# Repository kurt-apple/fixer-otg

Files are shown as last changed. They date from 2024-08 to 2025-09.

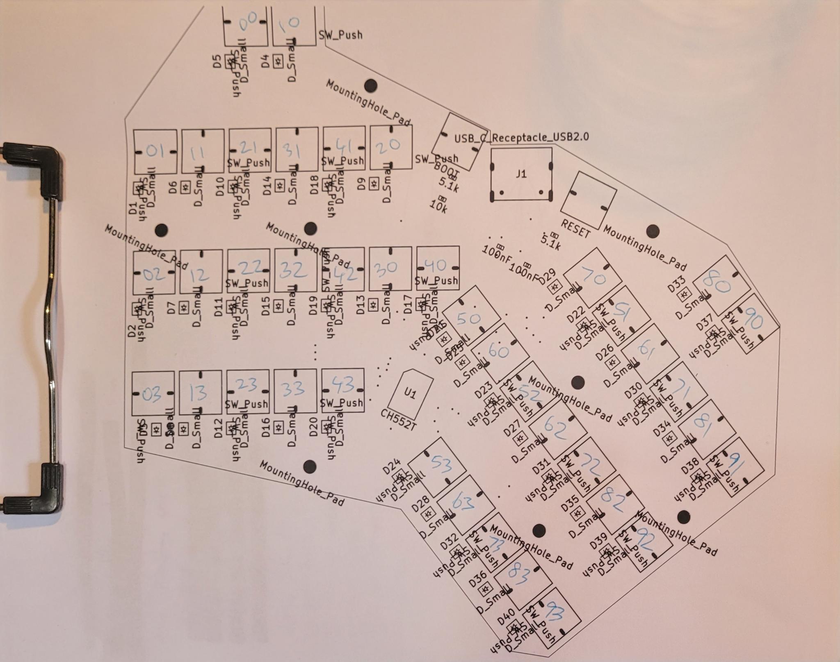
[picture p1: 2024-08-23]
pcb/layout.jpeg

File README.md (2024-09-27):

# fixer-otg
- Fork of [ChrisChrisLoLo/pusheenz40](https://github.com/ChrisChrisLoLo/pusheenz40). Also gathered info from [idawgz32](https://github.com/ChrisChrisLoLo/idawgz32) and [bunchiez40](https://github.com/ChrisChrisLoLo/bunchiez40).
- Layout is all-new, and design emphasizes ultra portable, small form factor while still having a fairly sane key map.
- Encased in epoxy for maximum durability and true pocketability
- Blog posts hosted on [Obsidian Publish](https://publish.obsidian.md/kurt/Maps/Fixer+OTG).
- **SHOWCASE MEDIA** is [here!](https://publish.obsidian.md/kurt/Pages/Fixer+OTG/Fixer+OTG+-+Showcase)
- FAK Firmware is [here!](https://github.com/kurt-apple/fak)

Fixer OTG Keyboard
Poser

# Keyboard Design
As a parent, I often find myself "nap-trapped" but still needing to do computer work. After trying several Android touchscreen keyboards I have concluded that my fingers are not up for the task anymore. However, I still require a handheld form factor. More recently I spotted the uConsole from ClockworkPi and while it looks neat, I reason that if I have to wait many months to receive one, I might as well challenge myself to DIY. What could go wrong? 

The intent is to use these schematics (bunchiez40, pusheenz40, and idawgz32) as a launching-off point for an ambitious, DIY pocket keyboard, which will later evolve into a "deck" or "pocket" pc. Some requirements are currently listed in the [TODOs](TODO.md).

# Status
- prototype keyboard PCBs were ordered, arrived, I broke board 1 and board 2 is alive and well!
- Layout and firmware are made and I can achieve ~22 WPM on this layout!
- I've got my eyes set on a few display modules and I am interested in designing a CM4 carrier or picking another small SBC to dedicate to the cyberdeck project.

# Navigating the KiCad Files
I used a plugin called "Hierarchical-PCB" which allowed me to define a subcircuit for `switch_module` in separate `kicad_pcb` and `kicad_sch` files, then copy the layout specified in that `kicad_pcb` file whenever a hierarchical sheet of the same name is placed in the schematic of another PCB. The `switch_module` contains through-holes, diode positioning, and the necessary tracks for a single key.

> [!Warning]
> "Hierarchical-PCB" does not yet support nested hierarchical sheets. I forked the project and I want to try to add this support at a later date. Nevertheless, this plugin was VERY helpful in both making the schematic visually less noisy and also in quickly laying out tedious portions of the keyboard PCB.

To open the design I am using currently, please open the main `kicad_pcb` file titled `fixer-otg.kicad_pcb`.

# Making One
- DM me on Discord (@present_day) to check if I have any boards remaining
- Get yourself some Kailh Mute Micro Switches (42x)
- Fork my FAK repo for the firmware code, and modify however much you wish.
- Gather your soldering supplies
- My provided manufacturing files (gerber, drilling, BOM) are specifically for JLCPCB. If you want to print them at a different company you might have to output your own manufacturing files. Please note that there were a few minor corrections/alterations JLC made before finalizing their production file and proceeding to manufacturing. I am new at this - your experience may vary.
- All but the switches are placed/assembled by JLC.
- Receive your board(s)
- Recommended: flash firmware and short out each key by hand to make sure the keys work.
- Clone or fork the firmware repo and read code/make any customizations as you wish.
- `python fak.py compile -kb fixer-otg`
- plug in the board while holding the BOOT key (left of usb port)
- `python fak.py flash -kb fixer-otg`
- Solder the mute switches to each pad if you haven't done so already. Seal bottom of switches if you plan to epoxy (at your own risk!)
- Test it out

# Firmware Dependencies (Arch)
- python
- meson
- sdcc
- nickel

# BOM
This is the BOM. Note that most PCB prototype services have a minimum order quantity of around 5.
|  Comment | JLCPCB Part # | QTY | Price 5 Boards |
|---|---|---| --- |
| USB C Port | C165948 | 5 | $0.779 |
| CH552T | C111367 | 5 | $2.543 |
| 100nF Capacitor | C1525 | 10 | $0.012 |
| 5.1k Resistor | C25905 | 10 | $0.005 |
| 10k Resistor | C25744 | 5 | $0.003 |
| Diode | C2128 | 200 | $1.78 |

Some notes about my order and costs:
- PCB cost $19.60 in total for 5 boards.
- assembly cost $21.96 for 5 boards.
- shipping from JLC cost $22.80 to USA.
- the cost for switches varies widely; I bought from Kailh directly however Alibaba/Aliexpress have bulk lots of Kailh Micro switches for much cheaper.

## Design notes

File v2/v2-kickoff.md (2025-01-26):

# Kickoff: Fixer V2
The new version will be completely redone.
- PG1316M
- DIY SMT Soldering
- Wireless Split

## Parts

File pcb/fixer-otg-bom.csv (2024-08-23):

Reference | Value | Datasheet | Footprint | Qty | DNP | JLCPCB Part#
C1,C2 | 100nF | ~ | Library:C_0402_1005Metric | 2 |  | C1525
D1,D2,D3,D4,D5,D6,D7,D8,D9,D10,D11,D12,D13,D14,D15,D16,D17,D18,D19,D20,D21,D22,D23,D24,D25,D26,D27,D28,D29,D30,D31,D32,D33,D34,D35,D36,D37,D38,D39,D40 | D_Small | ~ | Library:D_SOD-323 | 40 |  | C2128
J1 | USB_C_Receptacle_USB2.0 | https://www.usb.org/sites/default/files/documents/usb_type-c.zip | Library:USB_C_Receptacle_HRO_TYPE-C-31-M-12 | 1 |  | C165948
R1,R2 | 5.1k | ~ | Library:R_0402_1005Metric | 2 |  | C25905
R3 | 10k | ~ | Library:R_0402_1005Metric | 1 |  | C25744
U1 | CH552T | http://www.wch.cn/downloads/file/241.html | Library:TSSOP-20_4.4x6.5mm_P0.65mm | 1 |  | C111367

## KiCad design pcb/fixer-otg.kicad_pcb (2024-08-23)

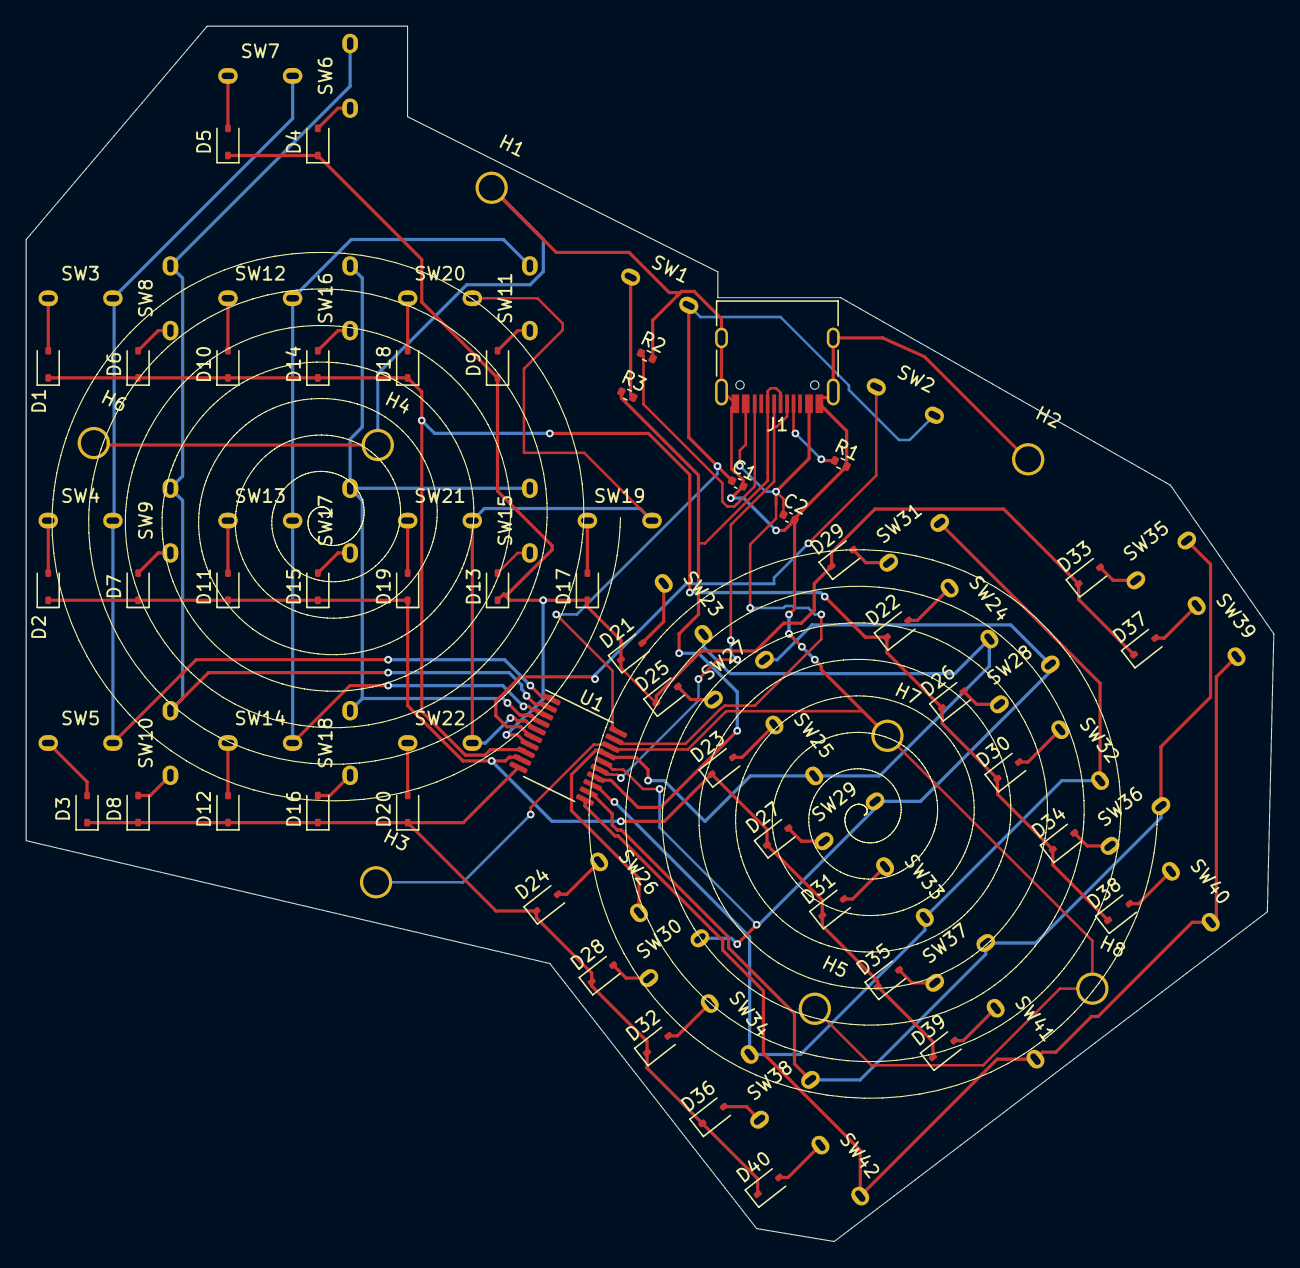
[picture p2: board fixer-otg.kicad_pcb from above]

Board: 2 copper layers, 96.5 x 94.0 mm, 97 parts (0 on the bottom side), 63 nets.

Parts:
C1, C2: 100nF; C_0402_1005Metric
D1, D2, D3, D4, D5, D6, D7, D8, D9, D10, D11, D12, D13, D14, D15, D16, D17, D18, D19, D20, D21, D22, D23, D24, D25, D26, D27, D28, D29, D30, D31, D32, D33, D34, D35, D36, D37, D38, D39, D40: D_Small; D_SOD-323
H1, H2, H3, H4, H5, H6, H7, H8: MountingHole_Pad; m1.6_hole
J1: USB_C_Receptacle_USB2.0; USB_C_Receptacle_HRO_TYPE-C-31-M-12
R1, R2: 5.1k; R_0402_1005Metric
R3: 10k; R_0402_1005Metric
SW1: BOOT; Button_Mute_Kailh
SW2: RESET; Button_Mute_Kailh
SW3, SW4, SW5, SW6, SW7, SW8, SW9, SW10, SW11, SW12, SW13, SW14, SW15, SW16, SW17, SW18, SW19, SW20, SW21, SW22, SW23, SW24, SW25, SW26, SW27, SW28, SW29, SW30, SW31, SW32, SW33, SW34, SW35, SW36, SW37, SW38, SW39, SW40, SW41, SW42: SW_Push; Button_Mute_Kailh
U1: CH552T; TSSOP-20_4.4x6.5mm_P0.65mm

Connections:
+3.3V: C1.1, SW1.2, SW2.2, U1.20 (V33)
BOOT: R3.2, SW1.1
CC1: J1.A5 (CC1), R1.1
CC2: J1.B5 (CC2), R2.1
GND: C1.2, C2.2, H1.1, H2.1, H3.1, H4.1, H5.1, H6.1, H7.1, H8.1, J1.A1 (GND), J1.A12 (GND), J1.B1 (GND), J1.B12 (GND), J1.S1 (SHIELD), R1.2, R2.2, U1.18 (GND/VSS)
unnamed: D1.2 (A), SW3.1
unnamed: D2.2 (A), SW4.1
unnamed: D3.2 (A), SW5.1
unnamed: D4.2 (A), SW6.1
unnamed: D5.2 (A), SW7.1
unnamed: D6.2 (A), SW8.1
unnamed: D7.2 (A), SW9.1
unnamed: D8.2 (A), SW10.1
unnamed: D9.2 (A), SW11.1
unnamed: D10.2 (A), SW12.1
unnamed: D11.2 (A), SW13.1
unnamed: D12.2 (A), SW14.1
unnamed: D13.2 (A), SW15.1
unnamed: D14.2 (A), SW16.1
unnamed: D15.2 (A), SW17.1
unnamed: D16.2 (A), SW18.1
unnamed: D17.2 (A), SW19.1
unnamed: D18.2 (A), SW20.1
unnamed: D19.2 (A), SW21.1
unnamed: D20.2 (A), SW22.1
unnamed: D21.2 (A), SW23.1
unnamed: D22.2 (A), SW24.1
unnamed: D23.2 (A), SW25.1
unnamed: D24.2 (A), SW26.1
unnamed: D25.2 (A), SW27.1
unnamed: D26.2 (A), SW28.1
unnamed: D27.2 (A), SW29.1
unnamed: D28.2 (A), SW30.1
unnamed: D29.2 (A), SW31.1
unnamed: D30.2 (A), SW32.1
unnamed: D31.2 (A), SW33.1
unnamed: D32.2 (A), SW34.1
unnamed: D33.2 (A), SW35.1
unnamed: D34.2 (A), SW36.1
unnamed: D35.2 (A), SW37.1
unnamed: D36.2 (A), SW38.1
unnamed: D37.2 (A), SW39.1
unnamed: D38.2 (A), SW40.1
unnamed: D39.2 (A), SW41.1
unnamed: D40.2 (A), SW42.1
RST: SW2.1, U1.6 (RST/T2EX_/CAP2_)
UDM: J1.A7 (D-), J1.B7 (D-), U1.15 (P3.7/UDM)
UDP: J1.A6 (D+), J1.B6 (D+), R3.1, U1.14 (P3.6/UDP)
VBUS: C2.1, J1.A4 (VBUS), J1.A9 (VBUS), J1.B4 (VBUS), J1.B9 (VBUS), U1.19 (VCC/VDD)
col1: SW3.2, SW4.2, SW5.2, SW7.2, U1.1 (P3.2/TXD1_/INT0/VBUS1/AIN3)
col2: SW6.2, SW8.2, SW9.2, SW10.2, U1.2 (P1.4/T2_/CAP1_/SCS/TIN2/UCC1/AIN1)
col3: SW11.2, SW12.2, SW13.2, SW14.2, U1.3 (P1.5/MOSI/PWM1/TIN3/UCC2/AIN2)
col4: SW15.2, SW16.2, SW17.2, SW18.2, U1.4 (P1.6/MISO/RXD1/TIN4)
col5: SW19.2, SW20.2, SW21.2, SW22.2, U1.5 (P1.7/SCK/TXD1/TIN5)
col6: SW23.2, SW24.2, SW25.2, SW26.2, U1.17 (P1.2/XI/RXD_)
col7: SW27.2, SW28.2, SW29.2, SW30.2, U1.16 (P1.3/XO/TXD_)
col8: SW31.2, SW32.2, SW33.2, SW34.2, U1.13 (P3.5/T1)
col9: SW35.2, SW36.2, SW37.2, SW38.2, U1.12 (P3.4/PWM2/RXD1_/T0)
col10: SW39.2, SW40.2, SW41.2, SW42.2, U1.11 (P3.3/INT1)
row1: D4.1 (K), D5.1 (K), D9.1 (K), D13.1 (K), D17.1 (K), D21.1 (K), D25.1 (K), D29.1 (K), D33.1 (K), D37.1 (K), U1.7 (P1.0/T2/CAP1/TIN0)
row2: D1.1 (K), D6.1 (K), D10.1 (K), D14.1 (K), D18.1 (K), D22.1 (K), D26.1 (K), D30.1 (K), D34.1 (K), D38.1 (K), U1.8 (P1.1/T2EX/CAP2/TIN1/VBUS2/AIN0)
row3: D2.1 (K), D7.1 (K), D11.1 (K), D15.1 (K), D19.1 (K), D23.1 (K), D27.1 (K), D31.1 (K), D35.1 (K), D39.1 (K), U1.9 (P3.1/PWM2_/TXD)
row4: D3.1 (K), D8.1 (K), D12.1 (K), D16.1 (K), D20.1 (K), D24.1 (K), D28.1 (K), D32.1 (K), D36.1 (K), D40.1 (K), U1.10 (P3.0/PWM1_/RXD)

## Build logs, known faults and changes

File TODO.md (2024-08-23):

# Todos
- Finish firmware rev1
- Test switch pads
- Solder one prototype
- Practice with layout

# Project goals
- Surface mount switches
- Crude USB host switcher
- Make sure ports are spaced apart
- Able to thumb type as well as normal type
- Trackball 
- Usable 
- Small LCD? And if small lcd, store notes locally?
- QD mount keyboard into deck
- Ergonomic angled offset
- Backlit
- Cheap to make
- bumps to ID keys in the dark

# Random ideas
- Hinged split

# Over the moon
- Bluetooth/Wi-Fi 
- CM4 on board
- Battery
- Some type of universal phone clamp on kb

# Absurd
- Cellular modem
- Inflatable handles/grips

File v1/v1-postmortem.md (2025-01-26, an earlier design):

# Fixer OTG v1 Postmortem
The keyboard overall is good but I know it can be a lot better.
I'm redesigning v2 from scratch to respond to many drawbacks and tradeoffs noted elsewhere about v1.

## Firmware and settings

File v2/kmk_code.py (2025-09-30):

print("Starting")

import busio
import board
from kmk.kmk_keyboard import KMKKeyboard; keyboard = KMKKeyboard()
from kmk.keys import KC, make_key
from kmk.scanners import DiodeOrientation

# from kb import data_pin
from kmk.modules.split import Split, SplitType, SplitSide
from kmk.modules.layers import Layers; keyboard.modules.append(Layers())
from kmk.modules.holdtap import HoldTap; keyboard.modules.append(HoldTap())
from kmk.modules.tapdance import TapDance; keyboard.modules.append(TapDance())
from kmk.modules.macros import Macros
from kmk.modules.combos import Combos, Chord
combos = Combos()
keyboard.modules.append(combos)

from kmk.hid import HIDModes
from kmk.hid import BLEHID

from storage import getmount

side = SplitSide.RIGHT if str(getmount('/').label)[-1] == 'R' else SplitSide.LEFT

keyboard.col_pins = (board.D10, board.D9, board.D8, board.D7)
keyboard.row_pins = (board.D0, board.D1, board.D2, board.D3, board.D6)

bluetoothInterface = BLEHID()
def BT(*args, **kwargs):
    bluetoothInterface.clear_bonds()
    bluetoothInterface.start_advertising()

# make_key(names=('CLEARBT',), on_press=BT, on_release=passthrough)

keyboard.diode_orientation = DiodeOrientation.COL2ROW

split = Split(
    split_flip=True,  # If both halves are the same, but column pins are flipped, set this True
    split_side=side,  # Sets if this is to SplitSide.LEFT or SplitSide.RIGHT, or use EE hands
    split_type=SplitType.BLE,  # Defaults to UART
)
keyboard.modules.append(split)

def left_and_right(abbreviation, lkeycode, rkeycode = None):
    if(rkeycode == None):
        rkeycode = lkeycode
    return [
        Chord((KC.L, abbreviation), lkeycode),
        Chord((KC.R, abbreviation), rkeycode)
    ]

knum = KC.MO(1)
knav = KC.MO(2)
kfnc = KC.MO(3)

# LEGEND
# ★ hold tap
# ☹ needs moved

_★A_LSFT   = KC.HT(KC.A,   KC.LSFT)
_★R_LSFT   = KC.HT(KC.R,   KC.LSFT)
_★T_LCMD = KC.HT(KC.T, KC.LCMD)
_★COMM_LCTL   = KC.HT(KC.COMM,   KC.LCTL)
_★K_MO2    = KC.HT(KC.K,   knav)
_★ENT_MO3  = KC.HT(KC.ENT, kfnc)
_★DOT_LALT   = KC.HT(KC.DOT,   KC.LALT)
_★ESC_MO1  = KC.HT(KC.ESC, knum)

combos.combos = [
    Chord((KC.S,      KC.L), KC.SCLN), # ; #! works
    Chord((KC.C,      KC.L), KC.COLN), # : #! works, awkward
    Chord((KC.E,      KC.Q), KC.EQL), # = #! works
    Chord((KC.B,      KC.S), KC.BSLS), # \| #! works but a little awkward
    Chord((KC.D,      KC.Q), KC.DQUO), # " works
    Chord((KC.S,      KC.Q), KC.QUOT), # ' works
    Chord((KC.E,      KC.X), KC.EXLM), # works
    Chord((_★A_LSFT, _★T_LCMD), KC.AT), # @ #! does not work
    Chord((KC.O,      KC.C), KC.POUND), #! does not work
    Chord((_★A_LSFT, KC.M), KC.AMPR), #! does not work
    Chord((_★A_LSFT, KC.E, KC.I, KC.U), KC.MO(4)), #! untested
    Chord((KC.E,      KC.O), KC.TAB, per_key_timeout=True, timeout=75),
    Chord((KC.I,      KC.O), KC.BSPC, per_key_timeout=True, timeout=75),
    Chord((_★T_LCMD,  KC.L), KC.SPC, per_key_timeout=True, timeout=75)
]

combos.combos.extend(left_and_right(KC.A, KC.LEFT_ANGLE_BRACKET, KC.RIGHT_ANGLE_BRACKET))
combos.combos.extend(left_and_right(KC.B, KC.LEFT_CURLY_BRACE,   KC.RIGHT_CURLY_BRACE))
combos.combos.extend(left_and_right(KC.P, KC.LEFT_PAREN,         KC.RIGHT_PAREN))
combos.combos.extend(left_and_right(KC.F, KC.LBRACKET,           KC.RBRACKET))

ast = KC.ASTR
_ₓₓₓ_ = KC.NO
hidsw = KC.HID_SWITCH
blerf = KC.BLE_REFRESH

# todos
# - perhaps left consonant scrabble score should be higher avg.
# - consider moving some consonants from left to right
# move z to right
# - ensure ZE
# - ensure ZO
# - ensure IZ
# - ensure WH

# tests
# hope chop
# size what
# who where
# how for
# the

# required changes
# add LCMD maybe right hand

base_layer = [
                        KC.Z,       KC.X,                   KC.Q,       KC.J,#3
            KC.W,       KC.D,       KC.F,                   KC.Y,       KC.V,      KC.B,#9
_ₓₓₓ_,      KC.U,       KC.E,       KC.O,                   KC.L,       KC.S,      KC.N,       _ₓₓₓ_,#17
_★A_LSFT,   KC.P,       _★K_MO2,    KC.G,                   KC.M,       KC.C,      KC.H,       _★R_LSFT,#25
_★COMM_LCTL,            _★ESC_MO1,  KC.I,                   _★T_LCMD,   _★ENT_MO3,             _★DOT_LALT
]
num_layer = [
                        KC.GRV,     KC.TILD,                KC.SLSH,    ast,
            _ₓₓₓ_,      _ₓₓₓ_,      KC.DLR,                 KC.N7,      KC.N8,      KC.N9,
_ₓₓₓ_,      KC.PIPE,    KC.CIRC,    KC.PERC,                KC.N4,      KC.N5,      KC.N6,      KC.MINS,
_ₓₓₓ_,      _ₓₓₓ_,      _ₓₓₓ_,      _ₓₓₓ_,                  KC.N1,      KC.N2,      KC.N3,      KC.PLUS,
_ₓₓₓ_,                  _ₓₓₓ_,      _ₓₓₓ_,                  _ₓₓₓ_,      KC.N0,                  _ₓₓₓ_
]
nav_layer = [
                        _ₓₓₓ_,      _ₓₓₓ_,                  _ₓₓₓ_,      _ₓₓₓ_,
            _ₓₓₓ_,      _ₓₓₓ_,      KC.PGUP,                _ₓₓₓ_,      KC.UP,      _ₓₓₓ_,
KC.ESC,     _ₓₓₓ_,      _ₓₓₓ_,      KC.TAB,                 KC.LEFT,    KC.DOWN,    KC.RIGHT,   _ₓₓₓ_,
_ₓₓₓ_,      _ₓₓₓ_,      _ₓₓₓ_,      KC.PGDN,                _ₓₓₓ_,      KC.HOME,    KC.END,     _ₓₓₓ_,
KC.TRNS,                _ₓₓₓ_,      _ₓₓₓ_,                  _ₓₓₓ_,      _ₓₓₓ_,                  _ₓₓₓ_
]

F_layer = [
                        KC.INS,     KC.PSCR,                KC.F10,     KC.F11,
            _ₓₓₓ_,      KC.LCTL,    _ₓₓₓ_,                  KC.F7,      KC.F8,      KC.F9,
_ₓₓₓ_,      _ₓₓₓ_,      _ₓₓₓ_,      _ₓₓₓ_,                  KC.F4,      KC.F5,      KC.F6,      KC.LALT,
_ₓₓₓ_,      _ₓₓₓ_,      _ₓₓₓ_,      _ₓₓₓ_,                  KC.F1,      KC.F2,      KC.F3,      _ₓₓₓ_,
hidsw,                  KC.DEL,     KC.F12,                 _ₓₓₓ_,      _ₓₓₓ_,                  blerf
]

# macros = [
#                  _ₓₓₓ_,  _ₓₓₓ_,         _ₓₓₓ_,    _ₓₓₓ_,
#           _ₓₓₓ_, _ₓₓₓ_,  _ₓₓₓ_,         _ₓₓₓ_,    _ₓₓₓ_,     _ₓₓₓ_,
# _ₓₓₓ_,    _ₓₓₓ_, _ₓₓₓ_,  _ₓₓₓ_,         _ₓₓₓ_,    _ₓₓₓ_,     _ₓₓₓ_,    _ₓₓₓ_,
# _ₓₓₓ_,    _ₓₓₓ_, _ₓₓₓ_,  _ₓₓₓ_,         _ₓₓₓ_,    _ₓₓₓ_,     _ₓₓₓ_,    _ₓₓₓ_,
# _ₓₓₓ_,           _ₓₓₓ_,  _ₓₓₓ_,         _ₓₓₓ_,    _ₓₓₓ_,               _ₓₓₓ_
# ]

def transpose(layer):
    return [
        layer[10],  layer[4],   layer[0],   layer[1],   layer[2],   layer[3],   layer[9],   layer[17],
        layer[18],  layer[11],  layer[5],   layer[6],   layer[7],   layer[8],   layer[16],  layer[25],
        layer[26],  layer[19],  layer[12],  layer[13],  layer[14],  layer[15],  layer[24],  layer[31],
        _ₓₓₓ_,      _ₓₓₓ_,      layer[20],  layer[21],  layer[22],  layer[23],  _ₓₓₓ_,      _ₓₓₓ_,
        _ₓₓₓ_,      _ₓₓₓ_,      layer[27],  layer[28],  layer[29],  layer[30],  _ₓₓₓ_,      _ₓₓₓ_]


keyboard.keymap = [
# BASE
transpose(base_layer),
# NUM
transpose(num_layer),
# # NAV
transpose(nav_layer),
# MACROS
# transpose(macros),
]

layer_names_list = [
"Base",
"Num",
"Nav",
"F",
# "MACRO"
# "Nav", "Num",
]

if __name__ == '__main__':

    if side == SplitSide.LEFT:
        # should work, according to github issues chatter, but doesn't
        # - secondary_hid_type appears to be unimplemented
        # keyboard.go(hid_type=HIDModes.USB, secondary_hid_type=HIDModes.BLE, ble_name='fixer2')
        # fallback if above config does not work
        keyboard.go(hid_type=HIDModes.BLE, ble_name='fixer2')
    else:
        keyboard.go()

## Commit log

2024-08-23 fixer otg kicad
    [fixer-otg-B_Cu.gbl, fixer-otg-B_Mask.gbs, fixer-otg-B_Paste.gbp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]
2024-08-23 manufacturing directory
    [fixer-otg-B_Cu.gbl, fixer-otg-B_Mask.gbs, fixer-otg-B_Paste.gbp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]
2024-08-23 BOM table
2025-03-19 latest firmware config for v2 fixer board...
    [kmk_code.py]
2025-09-30 Latest kmk_code.py for fixer-v2
    [kmk_code.py]
